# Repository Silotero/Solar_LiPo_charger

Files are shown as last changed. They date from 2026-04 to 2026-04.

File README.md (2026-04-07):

# Solar_LiPo_charger
Solar panel battery charger

This is a battery charger that uses solar panels for the charging. It has a max charging input to the batteries of 4 A. It is also capable of outputing up to 15W of power at 5V 3A at its USB-C port. It also has a screw terminal with the same output capabilities.

The charging IC that takes care of taking the solar input (which must be 2 panels in series, the rest, up to 20 of such pairs, in parallel), making the constant-current/constant-voltage work is the CN3791. The IC responsible for making sure that the batteries don't get overcharged, overdischarged or shorted is the AP9101CK6. It also uses the PAM2423 boost converter to achieve the 5V output on the screw terminal as well as the USB-C port. The announcement of the USB-C capabilities is done via 10k ohm resistors pulled up to VCC on the CC pins.

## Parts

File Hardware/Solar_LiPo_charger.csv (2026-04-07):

Reference | Qty | Value | DNP | Exclude from BOM | Exclude from Board | Footprint | Datasheet
C1 | 1 | 10n |  |  |  | Capacitor_SMD:C_0603_1608Metric | ~
C2 | 1 | 2.2n |  |  |  | Capacitor_SMD:C_0603_1608Metric | ~
C3 | 1 | 47p |  |  |  | Capacitor_SMD:C_0603_1608Metric | ~
C4.C18 | 2 | 4.7u |  |  |  | Capacitor_SMD:C_0603_1608Metric | ~
C5 | 1 | 470u |  |  |  | Capacitor_THT:CP_Radial_D10.0mm_P5.00mm | ~
C6 | 1 | 2200u |  |  |  | Capacitor_THT:CP_Radial_D10.0mm_P5.00mm | ~
C7.C8.C17 | 3 | 22u |  |  |  | Capacitor_SMD:C_0603_1608Metric | ~
C9.C10.C19.C20.C22 | 5 | 10u |  |  |  | Capacitor_SMD:C_0603_1608Metric | ~
C11.C16 | 2 | 100n |  |  |  | Capacitor_SMD:C_0603_1608Metric | ~
C12 | 1 | 220n |  |  |  | Capacitor_SMD:C_0603_1608Metric | ~
C13.C15 | 2 | 10u |  |  |  | Capacitor_THT:CP_Radial_D4.0mm_P2.00mm | ~
C14.C21 | 2 | 470n |  |  |  | Capacitor_SMD:C_0603_1608Metric | ~
D1.D4 | 2 | SL82-3G |  |  |  | Diode_SMD:D_SMC | https://www.vishay.com/docs/88751/ss32.pdf
D2.D3 | 2 | LED |  |  |  | Diode_SMD:D_0603_1608Metric | ~
D5 | 1 | SMAJ5.0A |  |  |  | Diode_SMD:D_SMA | https://www.littelfuse.com/media?itemid=75e32973-b177-4ee3-a0ff-cedaf1abdb93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
D6.D7.D8.D9.D10.D11.D12.D13.D14.D15.D16.D17.D18.D19.D20.D21.D22.D23.D24.D25 | 20 | SS54 |  |  |  | Diode_SMD:D_SMA | https://www.vishay.com/docs/88751/ss32.pdf
H1.H2.H3.H5 | 4 | MountingHole_Pad |  | Wyklucz z BOM |  | MountingHole:MountingHole_2.2mm_M2_DIN965_Pad | ~
IC1 | 1 | CN3791 |  |  |  | SOP100P600X175-10N | http://www.consonance-elec.com/pdf/datasheet/DSE-CN3791.pdf
IC2 | 1 | PAM2423AECADJR |  |  |  | PAM2421AECADJR | https://www.diodes.com//assets/Datasheets/products_inactive_data/PAM2421_22_23.pdf
J1 | 1 | Battery_connector |  |  |  | TerminalBlock_Phoenix:TerminalBlock_Phoenix_MKDS-1,5-2-5.08_1x02_P5.08mm_Horizontal | ~
J2.J3 | 2 | Solar connectors |  |  |  | Connector_PinHeader_2.54mm:PinHeader_1x20_P2.54mm_Vertical | ~
J4 | 1 | USB_C_Receptacle_USB2.0_16P |  |  |  | Connector_USB:USB_C_Receptacle_GCT_USB4105-xx-A_16P_TopMnt_Horizontal | https://www.usb.org/sites/default/files/documents/usb_type-c.zip
J5 | 1 | Conn_01x02_Pin |  |  |  | Connector_PinHeader_1.27mm:PinHeader_1x02_P1.27mm_Vertical | ~
J6 | 1 | 5v_out |  |  |  | TerminalBlock_Phoenix:TerminalBlock_Phoenix_MKDS-1,5-2-5.08_1x02_P5.08mm_Horizontal | ~
L1 | 1 | 2.2u |  |  |  | Inductors:DR127 | ~
L2 | 1 | 22u |  |  |  | Inductors:HCM1A1307V2-220-R | ~
Q1 | 1 | PMOS |  |  |  | Package_SO:SO-8_3.9x4.9mm_P1.27mm | https://ngspice.sourceforge.io/docs/ngspice-html-manual/manual.xhtml#cha_MOSFETs
Q2.Q3 | 2 | NMOS |  |  |  | Package_SO:SOP-8_3.76x4.96mm_P1.27mm | https://ngspice.sourceforge.io/docs/ngspice-html-manual/manual.xhtml
R1.R8 | 2 | 51k |  |  |  | Resistor_SMD:R_0805_2012Metric | ~
R2 | 1 | 15k |  |  |  | Resistor_SMD:R_0805_2012Metric | ~
R3.R4 | 2 | 10k |  |  |  | Resistor_SMD:R_0805_2012Metric | ~
R5 | 1 | 470 |  |  |  | Resistor_SMD:R_0805_2012Metric | ~
R6 | 1 | 120 |  |  |  | Resistor_SMD:R_0805_2012Metric | ~
R7 | 1 | 300k |  |  |  | Resistor_SMD:R_0805_2012Metric | ~
R9 | 1 | 0.03 |  |  |  | Resistor_SMD:R_1206_3216Metric | ~
R10 | 1 | 5.1k |  |  |  | Resistor_SMD:R_0805_2012Metric | ~
R11 | 1 | 2.7k |  |  |  | Resistor_SMD:R_0805_2012Metric | ~
R12 | 1 | 330 |  |  |  | Resistor_SMD:R_0805_2012Metric | ~
U2 | 1 | AP9101CK6 |  |  |  | Package_TO_SOT_SMD:SOT-23-6 | https://www.diodes.com/assets/Datasheets/AP9101C.pdf

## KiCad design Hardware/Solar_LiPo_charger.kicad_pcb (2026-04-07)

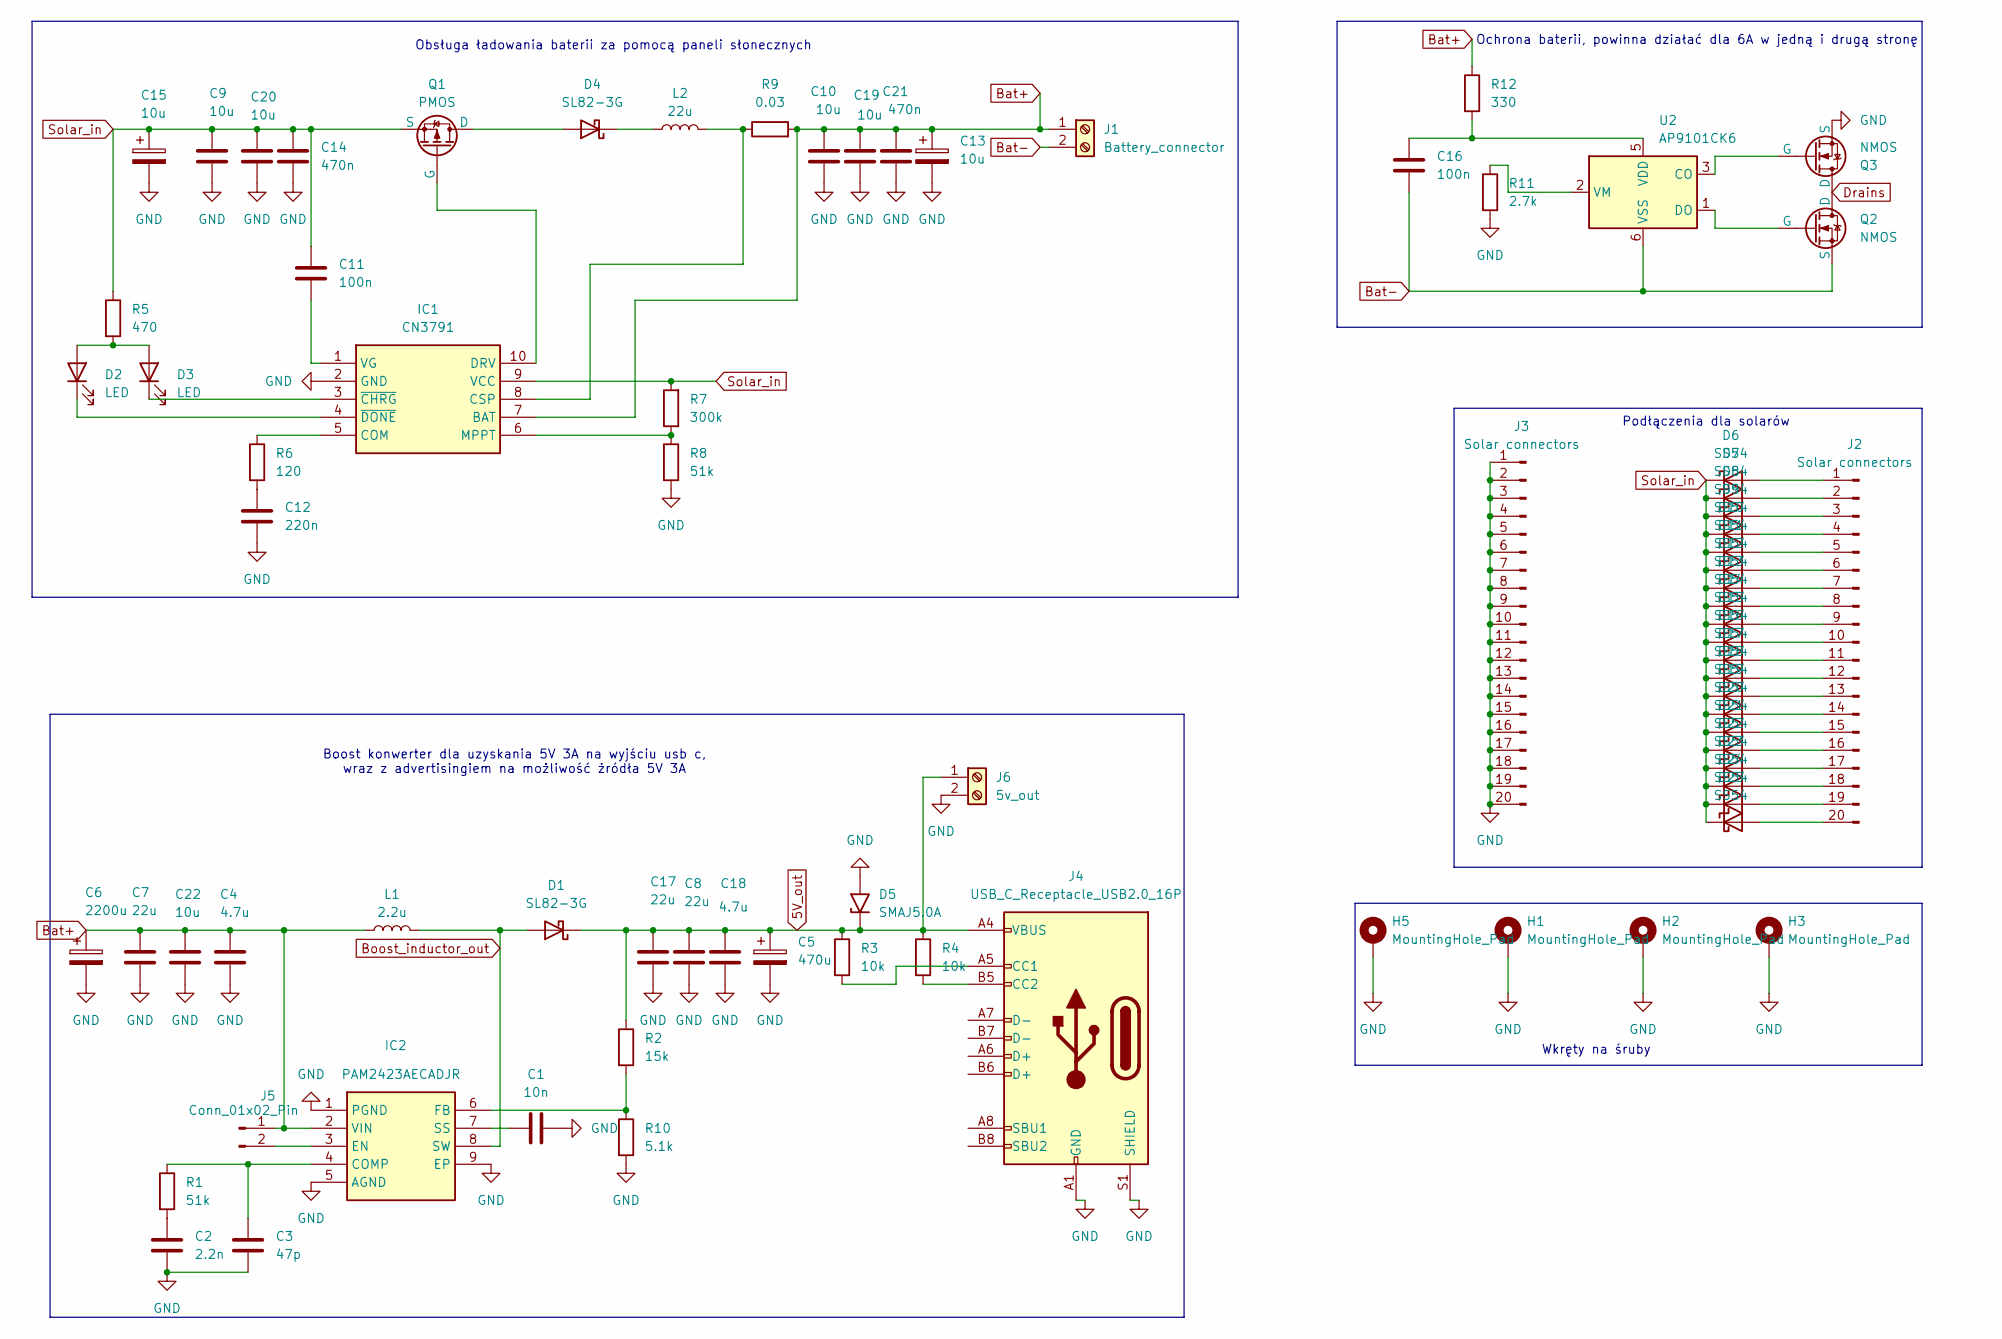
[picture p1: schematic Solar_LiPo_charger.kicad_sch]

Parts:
C1: 10n; C_0603_1608Metric
C2: 2.2n; C_0603_1608Metric
C3: 47p; C_0603_1608Metric
C4, C18: 4.7u; C_0603_1608Metric
C5: 470u; CP_Radial_D10.0mm_P5.00mm
C6: 2200u; CP_Radial_D10.0mm_P5.00mm
C7, C8, C17: 22u; C_0603_1608Metric
C9, C10, C19, C20, C22: 10u; C_0603_1608Metric
C11, C16: 100n; C_0603_1608Metric
C12: 220n; C_0603_1608Metric
C13, C15: 10u; CP_Radial_D4.0mm_P2.00mm
C14, C21: 470n; C_0603_1608Metric
D1, D4: SL82-3G; D_SMC
D2, D3: LED; D_0603_1608Metric
D5: SMAJ5.0A; D_SMA
D6, D7, D8, D9, D10, D11, D12, D13, D14, D15, D16, D17, D18, D19, D20, D21, D22, D23, D24, D25: SS54; D_SMA
H1, H2, H3, H5: MountingHole_Pad; MountingHole_2.2mm_M2_DIN965_Pad
IC1: CN3791; SOP100P600X175-10N; Manufacturer_Part_Number CN3791
IC2: PAM2423AECADJR; PAM2421AECADJR; Manufacturer_Part_Number PAM2421AECADJR; Mouser Part Number 621-PAM2421AECADJR
J1: Battery_connector; TerminalBlock_Phoenix_MKDS-1,5-2-5.08_1x02_P5.08mm_Horizont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
J2, J3: Solar connectors; PinHeader_1x20_P2.54mm_Vertical
J4: USB_C_Receptacle_USB2.0_16P; USB_C_Receptacle_GCT_USB4105-xx-A_16P_TopMnt_Horizontal
J5: Conn_01x02_Pin; PinHeader_1x02_P1.27mm_Vertical
J6: 5v_out; TerminalBlock_Phoenix_MKDS-1,5-2-5.08_1x02_P5.08mm_Horizont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
L1: 2.2u; DR127
L2: 22u; HCM1A1307V2-220-R
Q1: PMOS; SO-8_3.9x4.9mm_P1.27mm
Q2, Q3: NMOS; SOP-8_3.76x4.96mm_P1.27mm
R1, R8: 51k; R_0805_2012Metric
R2: 15k; R_0805_2012Metric
R3, R4: 10k; R_0805_2012Metric
R5: 470; R_0805_2012Metric
R6: 120; R_0805_2012Metric
R7: 300k; R_0805_2012Metric
R9: 0.03; R_1206_3216Metric
R10: 5.1k; R_0805_2012Metric
R11: 2.7k; R_0805_2012Metric
R12: 330; R_0805_2012Metric
U2: AP9101CK6; SOT-23-6

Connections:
5V_out: C5.1, C8.1, C17.1, C18.1, D1.1 (K), D5.1 (A1), J4.A4 (VBUS), J4.A9 (VBUS), J4.B4 (VBUS), J4.B9 (VBUS), J6.1, R2.1, R3.1, R4.1
Bat+: C4.1, C6.1, C7.1, C10.1, C13.1, C19.1, C21.1, C22.1, IC1.7 (BAT), IC2.2 (VIN), J1.1, J5.1, L1.1, R9.2, R12.1
Bat-: C16.2, J1.2, Q2.3 (S), U2.6 (VSS)
Boost_inductor_out: D1.2 (A), IC2.8 (SW), L1.2
Drains: Q2.1 (D), Q3.1 (D)
GND: C1.2, C2.2, C3.2, C4.2, C5.2, C6.2, C7.2, C8.2, C9.2, C10.2, C12.2, C13.2, C14.2, C15.2, C17.2, C18.2, C19.2, C20.2, C21.2, C22.2, D5.2 (A2), H1.1, H2.1, H3.1, H5.1, IC1.2 (GND), IC2.1 (PGND), IC2.5 (AGND), IC2.9 (EP), J3.1, J3.2, J3.3, J3.4, J3.5, J3.6, J3.7, J3.8, J3.9, J3.10, J3.11, J3.12, J3.13, J3.14, J3.15, J3.16, J3.17, J3.18, J3.19, J3.20, J4.A1 (GND), J4.A12 (GND), J4.B1 (GND), J4.B12 (GND), J4.S1 (SHIELD), J6.2, Q3.3 (S), R8.2, R10.2, R11.2
unnamed: C2.1, R1.2
unnamed: C12.1, R6.2
unnamed: D2.2 (A), D3.2 (A), R5.2
unnamed: D2.1 (K), IC1.4 (~DONE)
unnamed: D3.1 (K), IC1.3 (~CHRG)
unnamed: D4.2 (A), Q1.1 (D)
unnamed: D4.1 (K), L2.1
unnamed: D6.2 (A), J2.1
unnamed: D7.2 (A), J2.2
unnamed: D8.2 (A), J2.3
unnamed: D9.2 (A), J2.4
unnamed: D10.2 (A), J2.5
unnamed: D11.2 (A), J2.6
unnamed: D12.2 (A), J2.7
unnamed: D13.2 (A), J2.8
unnamed: D14.2 (A), J2.9
unnamed: D15.2 (A), J2.10
unnamed: D16.2 (A), J2.11
unnamed: D17.2 (A), J2.12
unnamed: D18.2 (A), J2.13
unnamed: D19.2 (A), J2.14
unnamed: D20.2 (A), J2.15
unnamed: D21.2 (A), J2.16
unnamed: D22.2 (A), J2.17
unnamed: D23.2 (A), J2.18
unnamed: D24.2 (A), J2.19
unnamed: D25.2 (A), J2.20
unnamed: IC1.5 (COM), R6.1
unnamed: IC1.8 (CSP), L2.2, R9.1
unnamed: IC1.10 (DRV), Q1.2 (G)
unnamed: IC1.6 (MPPT), R7.1, R8.1
unnamed: C11.2, IC1.1 (VG)
unnamed: C3.1, IC2.4 (COMP), R1.1
unnamed: IC2.3 (EN), J5.2
unnamed: IC2.6 (FB), R2.2, R10.1
unnamed: C1.1, IC2.7 (SS)
unnamed: J4.A5 (CC1), R3.2
unnamed: J4.B5 (CC2), R4.2
unnamed: Q2.2 (G), U2.1 (DO)
unnamed: Q3.2 (G), U2.3 (CO)
unnamed: C16.1, R12.2, U2.5 (VDD)
unnamed: R11.1, U2.2 (VM)
Solar_in: C9.1, C11.1, C14.1, C15.1, C20.1, D6.1 (K), D7.1 (K), D8.1 (K), D9.1 (K), D10.1 (K), D11.1 (K), D12.1 (K), D13.1 (K), D14.1 (K), D15.1 (K), D16.1 (K), D17.1 (K), D18.1 (K), D19.1 (K), D20.1 (K), D21.1 (K), D22.1 (K), D23.1 (K), D24.1 (K), D25.1 (K), IC1.9 (VCC), Q1.3 (S), R5.1, R7.2

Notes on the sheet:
Ochrona baterii, powinna działać dla 6A w jedną i drugą stronę
Podłączenia dla solarów
Boost konwerter dla uzyskania 5V 3A na wyjściu usb c, wraz z advertisingiem na możliwość żródła 5V 3A
Obsługa ładowania baterii za pomocą paneli słonecznych
Wkręty na śruby

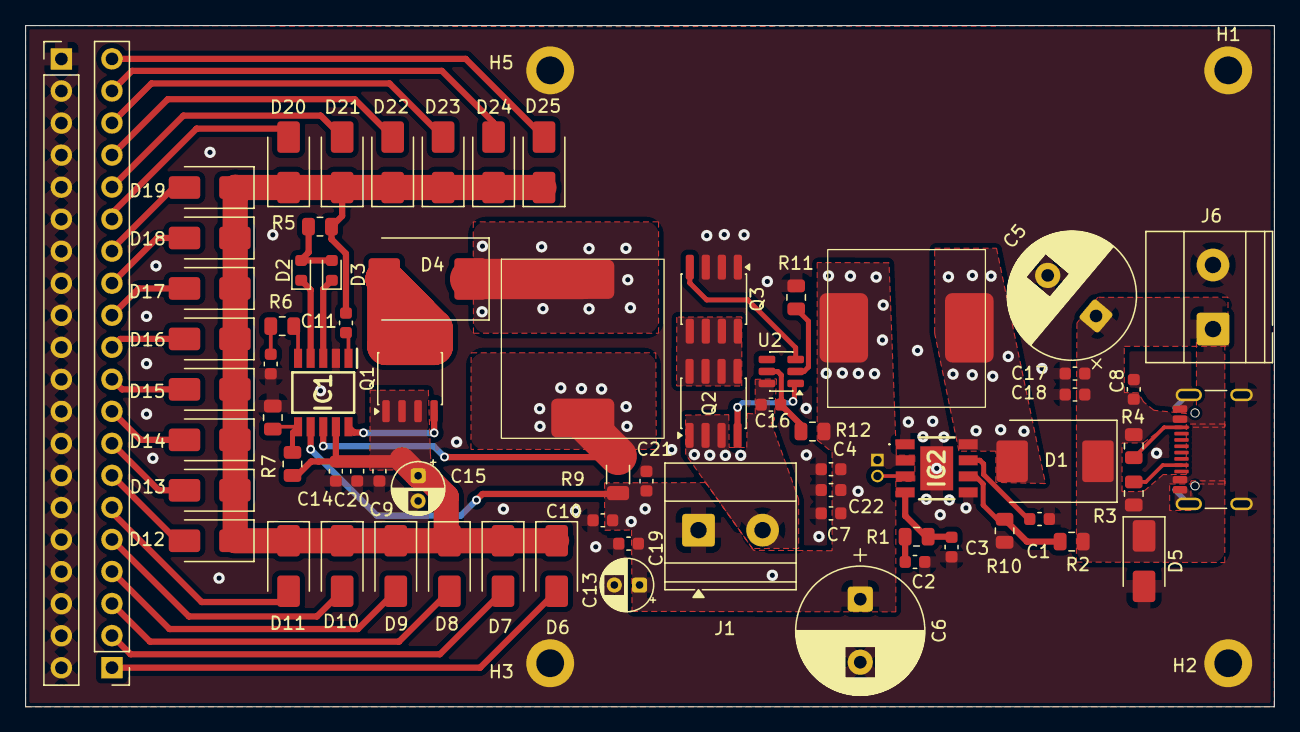
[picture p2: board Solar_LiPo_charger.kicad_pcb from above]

Board: 2 copper layers, 99.0 x 54.0 mm, 77 parts (0 on the bottom side), 49 nets.

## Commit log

2026-04-07 Added finished kicad project files
    [Solar_LiPo_charger.csv, Solar_LiPo_charger.kicad_pcb, Solar_LiPo_charger.kicad_sch]
2026-08-09 Fixed the working of a buck charger for the battery
    [Solar_LiPo_charger.kicad_sch]
